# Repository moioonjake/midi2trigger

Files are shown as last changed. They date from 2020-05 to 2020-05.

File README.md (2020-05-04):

# Midi2trigger
Midi2trigger is Arduino based Eurorack compatible module PCB for external MIDI device to trigger example drum modules. It’s a 100% non-commercial effort developed purely for own educational purposes where I’m trying to learn to understand schematics, KiCad and PCB making.

I’d like to hear your feedback if you built this module so I can improve these files.

# Design
Midi2trigger PCB measurements are following:
<br>width : 69.09 mm
<br>height : 80.26 mm

So it requires 14-16HP panel in Eurorack format.

On the front side, there's the 12 output jacks (thonkiconn) including leds and resistors.<br>
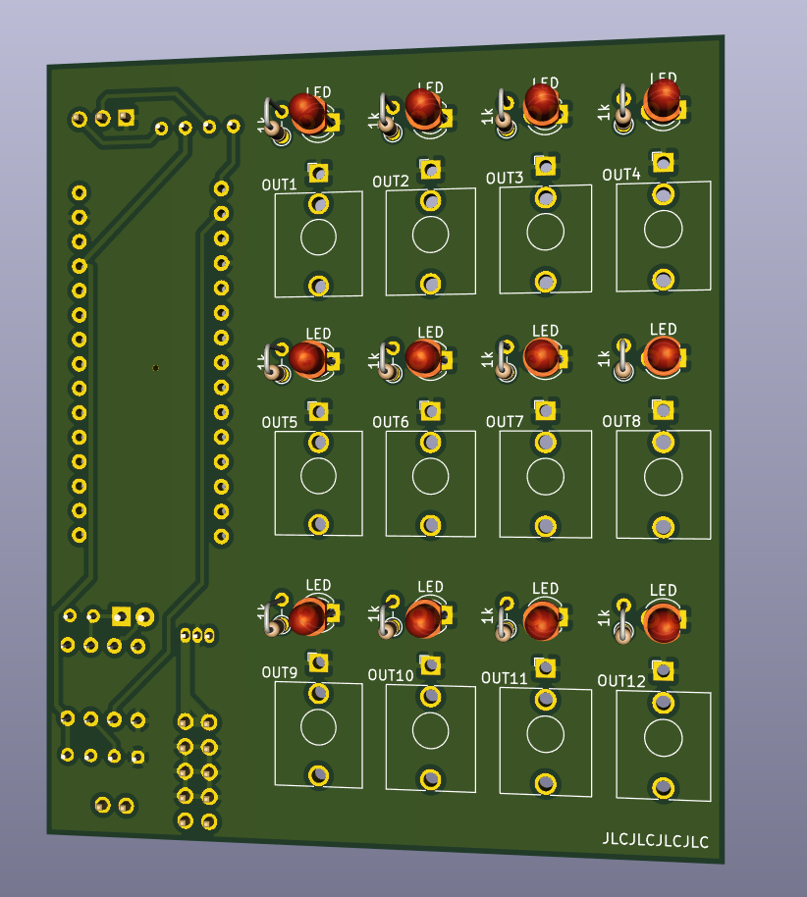
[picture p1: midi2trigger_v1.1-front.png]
image of midi2trigger front side


On the back side, there's the Arduino nano and other related components.<br>
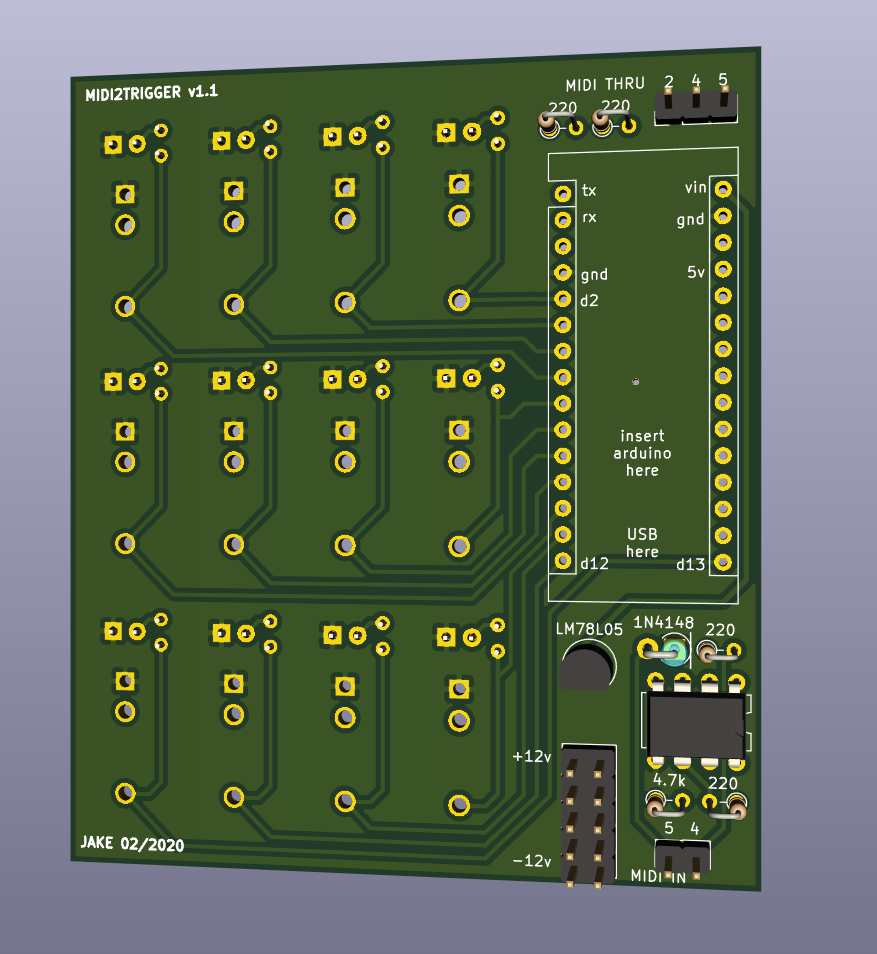
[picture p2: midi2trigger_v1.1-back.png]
image of midi2trigger back side


Arduino Pins are assigned in ascending order per semi tone starting with C of the specified octave for Pin2. For example: if set to 1 --> Pin2 = C1, Pin3 = C#1, Pin4 = D1 etc. (standard for most drum sequencers).
You can change the octave at the following line of code (change the int on "int octave = 1;" to example 3, "int octave = 3;"):

MIDI In and Thru has numbers on the PCB, those are MIDI connector Pin numbers. I used panel mounted MIDI connectors so there's no footprint on the PCB for those.

# Code
On the original code Midi thru was OFF ("MIDI.turnThruOff();"), since we have the MIDI >thru option on the PCB I have changed the code so that this is turn ON. If you do not need this option, change it back to OFF.

# Panel
Currently there’s no already made panel for this.

# Possible updates to v1.2
- Add: bypass caps to power line, 10uf to positive and GND before and after LM78L05.
- Change: route +5v line from LM78L05 to Arduino +5v instead VIN.
- Change: MIDI In/Thru change from pins to stereo 3.5mm jacks instead of MIDI connectors.

These can be added to current PCB with soldering capacitors straight to LM78L05 and cutting trace and adding jump wire to Arduino +5v pin.

# Notes
I have tested and verified this board and code.

Schematic parts has taken from default Arduino MIDI in/thru schematics and various places.

# Thanks to
- https://www.lookmumnocomputer.com, where I saw this concept on one of the youtube video
- Pieterv1 @circuitbenders.com, code and explanations that I found here: https://www.circuitbenders.co.uk/forum/index.php?topic=2656.0 

# License
Code (AVR projects): GPL3.0.<br><br>
Code (STM32F projects): MIT license.<br><br>
Hardware: cc-by-sa-3.0

# Disclaimer of liability
The material and information contained on this website is for general information purposes only. You should not rely upon the material or information on the website as a basis for making any business, legal or any other decisions.
Whilst I endeavour to keep the information up to date and correct, I make no representations or warranties of any kind, express or implied about the completeness, accuracy, reliability, suitability or availability with respect to the website or the information, products, services or related graphics contained on the website for any purpose. Any reliance you place on such material is therefore strictly at your own risk.

I will not be liable for any false, inaccurate, inappropriate or incomplete information presented on the website.

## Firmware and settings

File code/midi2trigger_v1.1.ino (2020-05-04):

// Original Roland CR-5000 Midi Sync and Midi Control Rev 02. 12-14 by Travis Thatcher
// Simplified for MIDI note to positive going triggers only using all 12 digital pins by Pieter Vochten (May-2016)
// https://www.circuitbenders.co.uk/forum/index.php?topic=2656.0


// Include the MIDI library (make sure it is installed in your Arduino IDE!
// Downloadable at: http://playground.arduino.cc/Main/MIDILibrary
#include "MIDI.h"
MIDI_CREATE_DEFAULT_INSTANCE(); // Create a default, nameless MIDI instance for handling MIDI events

#define NUMTRIGS 12 // This code will use all 12 digital output pins

#define TRIGGER_TIME 10  // this defines the trigger length in ms (edit as needed)

// This code uses 12 pins starting from Pin2 up to Pin13
// Pin 13 can be used for debugging because on most Arduino boards, it is connected to a built-in LED
int triggerPins[] = {2, 3, 4, 5, 6, 7, 8, 9, 10, 11, 12, 13};   // Create an array of 12 integers resembling the Pin numbers
// Create an array in which the hold times (timestamps in ms) for every trigger PIN will be stored (initially all set to zero)
int triggerTimes[] = {0, 0, 0, 0, 0, 0, 0, 0, 0, 0, 0, 0};
// Create an array containing the trigger state for every trigger PIN (initially all set to LOW, idle)
// Triggers will be set to HIGH (= +5v)
// Replace LOW / HIGH throughout the whole code to create inverted, negative going triggers (+5v idle, 0v triggers)
int triggerStates[] = {LOW, LOW, LOW, LOW, LOW, LOW, LOW, LOW, LOW, LOW, LOW, LOW};

int currentTime = 0;
int octave = 1;

byte incomingByte;
byte velocity;

void setup() {    // The following code is executed once for initialization
  //MIDI.turnThruOff();
  MIDI.turnThruOn();
  MIDI.begin(MIDI_CHANNEL_OMNI);  // this sets the midi channel, (0)= midi channel 1, (1)= midi channel 2 etc... or MIDI_CHANNEL_OMNI

  // Specify the octave; The octave can range from -2 to 8, depending on your needs.
  // Pins are assigned in ascending order per semi tone starting with C of the specified octave for Pin2
  // For example: if set to 1 --> Pin2 = C1, Pin3 = C#1, Pin4 = D1 etc. (standard for most drum sequencers)
  octave = 1;

  // Initialize the output pins. The Arduino uses + triggers (5v) so we set their initial state to Low (0v)

  pinMode(2, OUTPUT);
  digitalWrite(2, LOW);
  pinMode(3, OUTPUT);
  digitalWrite(3, LOW);
  pinMode(4, OUTPUT);
  digitalWrite(4, LOW);
  pinMode(5, OUTPUT);
  digitalWrite(5, LOW);
  pinMode(6, OUTPUT);
  digitalWrite(6, LOW);
  pinMode(7, OUTPUT);
  digitalWrite(7, LOW);
  pinMode(8, OUTPUT);
  digitalWrite(8, LOW);
  pinMode(9, OUTPUT);
  digitalWrite(9, LOW);
  pinMode(10, OUTPUT);
  digitalWrite(10, LOW);
  pinMode(11, OUTPUT);
  digitalWrite(11, LOW);
  pinMode(12, OUTPUT);
  digitalWrite(12, LOW);
  pinMode(13, OUTPUT);
  digitalWrite(13, LOW);

  // The built-in MIDI library is capable of filtering different types of MIDI events such as notes, control, sync...
  // This line specifies how to handle MIDI Note ON messages, referring to the function "void HandleNoteOn(..."
  MIDI.setHandleNoteOn(HandleNoteOn); // Set the handler for NoteOn events
}

void loop() {     // The following code is executed continuously after the setup
  MIDI.read();
  // Read in the current timestamp in ms and store it in currentTime
  currentTime = millis();

  // Check the state of the 12 triggers in a loop
  for (int i = 0; i < NUMTRIGS; i++) {  // "While i = 0 to i < 12 (number of triggers), do... for Array Position[i]" --> running through the arrays
    // For every HIGH trigger: compare its timestamp with the currentTime
    // Set the trigger state to LOW if the difference exceeds the specified TRIGGER_TIME
    if (triggerStates[i] == HIGH) {
      if (currentTime - triggerTimes[i] > TRIGGER_TIME) {
        digitalWrite(triggerPins[i], LOW);
        triggerStates[i] = LOW;
      }
    }
  }
}

void HandleNoteOn(byte channel, byte pitch, byte velocity) {  // this code is executed when MIDI notes are received
  // triggers!
  for (int i = 0; i < NUMTRIGS; i++) {
    if (pitch - 24 - (12 * octave) == i) {  // Calculate the PIN to match the incoming Pitch and the specified octave by subtracting a plural of "12"
      digitalWrite(triggerPins[i], HIGH);   // Set the actual matching PIN to HIGH (=> trigger active)
      triggerStates[i] = HIGH;              // Save the triggerState for this PIN in the triggerStates array
      triggerTimes[i] = currentTime;        // Save the current timestamp for this PIN in the triggerTimes array
    }
  }
}
